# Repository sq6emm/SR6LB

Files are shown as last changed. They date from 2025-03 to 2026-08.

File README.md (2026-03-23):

This is technical documentation of SR6LB microwave beacon

Meshtastic trace url: [https://lorastats.pl/Node/192968]

# Source code of beacon

[https://github.com/sq6emm/MGMBeacon]

# History

+ 2025-05-02 - beacon installed and running, however 23cm reported .816 instead of .830 and 10GHz reported .723 instead of .830, 24GHz reported +300kHz higher - confirmed that GPS is not working
+ 2025-05-05 - reported that 10GHz is down
+ 2025-05-19 - professional GPS antenna connected - beacon has lock and is transmiting digital JT4, 10GHz is still down
+ 2025-05-22 - beacon is DOWN, SR6LHZ / SR6XHZ is operational again, beacon went for maintanance to resolve the 10GHz issue
+ 2025-10-05 - beacon is UP, 10GHz was fixed (it seems there was some cold soldering), Meshtastic was added that is sending telemtry on voltage and current, there is sill issue with GPSDO, no digital mode is transmitted and frequency seems to jump from time to time when GPSDO looses its lock
+ 2025-12-04 - beacon is DOWN, it was identified that there is no power at the beacon (Meshtastic is also not working while its only dependency is 12V)
+ 2026-02-21 - beacon is UP, failed power supply replaced, GPSDO as a source of 10MHz replaced by OCXO, software updated beacon now transmits CW + JT4 + Q65, but on 10GHz and 24GHz during Q65 it does not work, source code glitch, to be fixed soon, Meshtastic configuration now include GPS location coordinates
+ 2026-03-21 - beacon is UP, GPSDO replaced with eCzasPL Receiver, but it is unable to get the fix... to strong EM field for 225kHz... so beacon is running CW only - one more plan to replace eCzasPL with GPS receiver (something new like NEO-F9M) just to get a clock information, Q65 code is fixed... but as there is no clock information unable to confirm (locally tested)

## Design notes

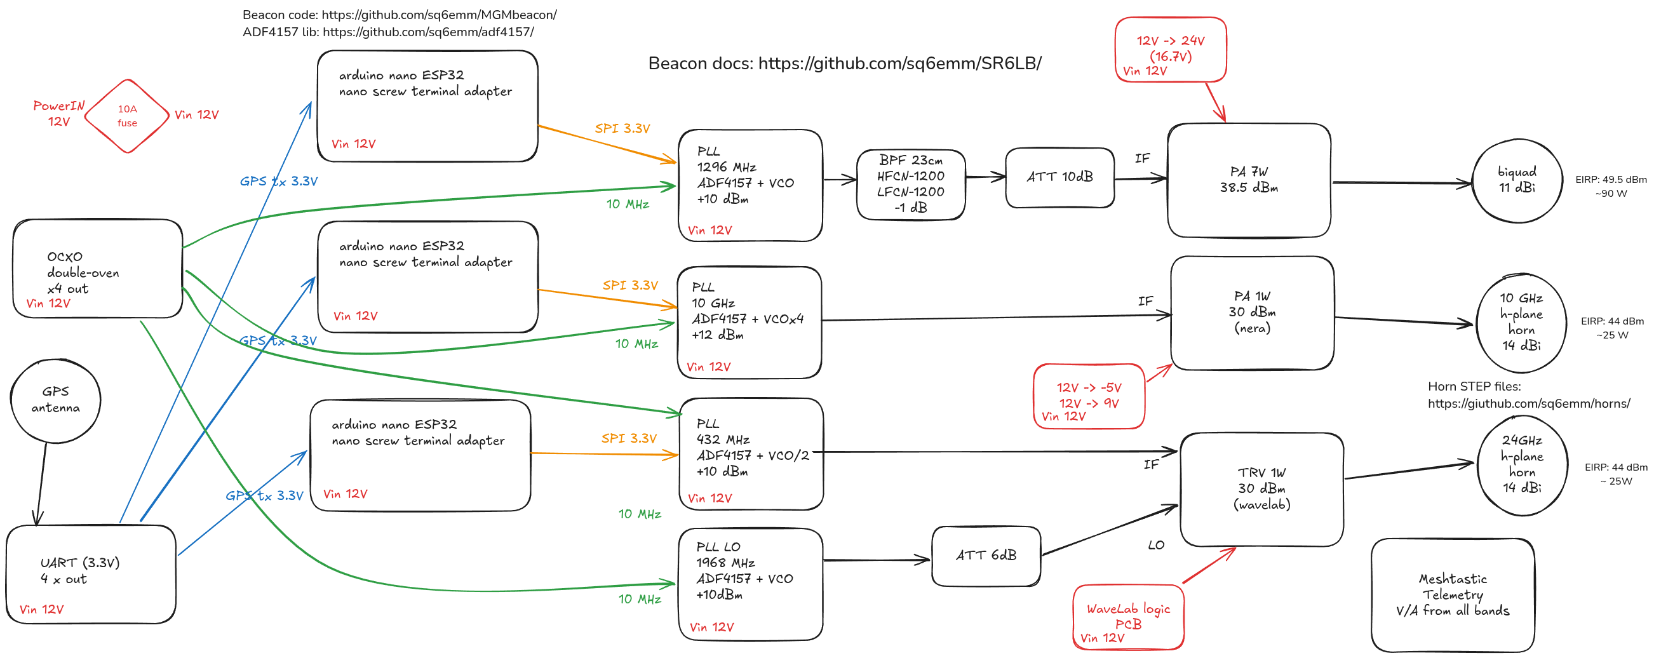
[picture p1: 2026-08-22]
SR6LB-block-diagram.png

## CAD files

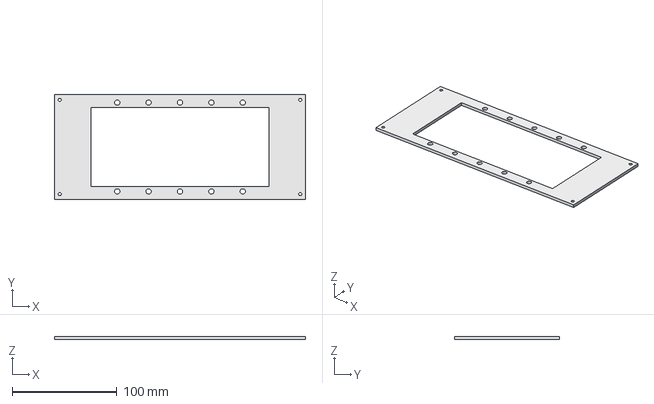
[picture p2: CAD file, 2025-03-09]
3dprints/beacon-10GHz PA mount.FCStd
240.0 x 100.0 x 3.00 mm

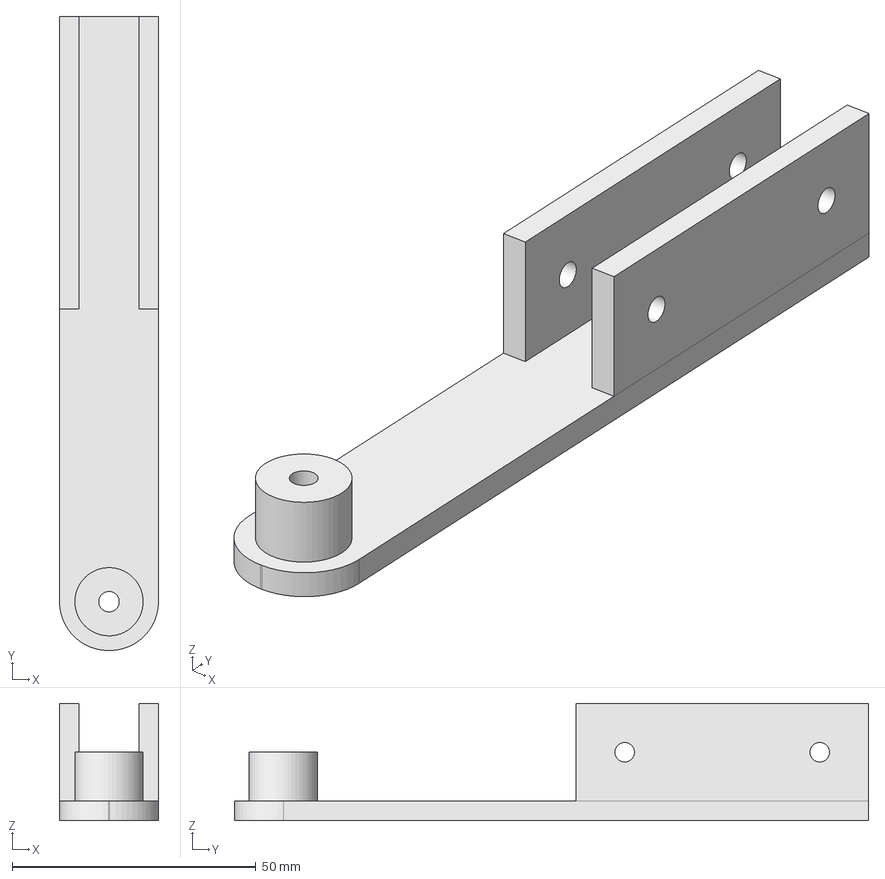
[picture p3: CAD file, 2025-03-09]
3dprints/beacon-24ghz-horn-mount-Body.step
20.3 x 130.0 x 24.0 mm

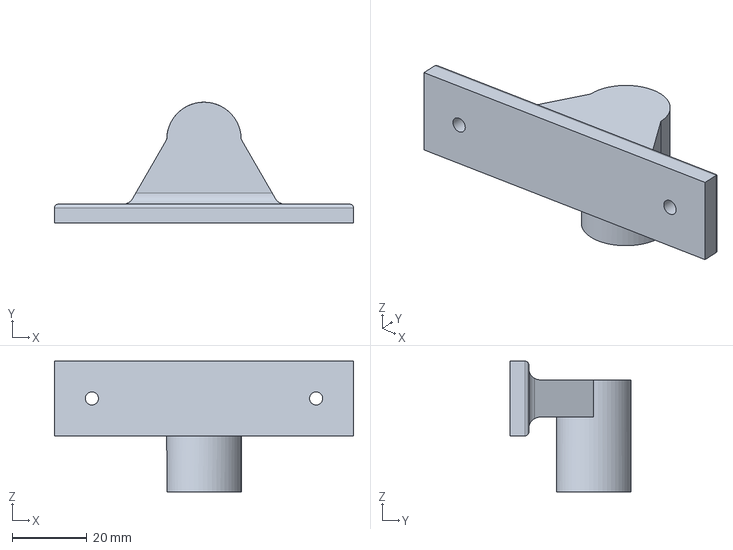
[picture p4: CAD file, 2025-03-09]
3dprints/beacon-mocowanie-biquad.FCStd
80.0 x 32.3 x 35.0 mm

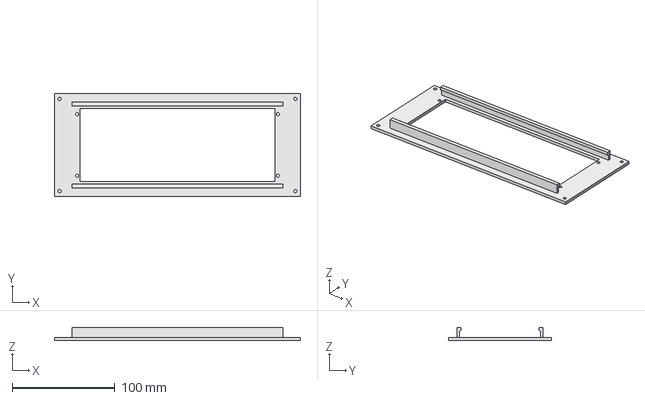
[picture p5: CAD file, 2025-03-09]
3dprints/beacon-radiator2-Body.step
240.0 x 100.0 x 12.5 mm

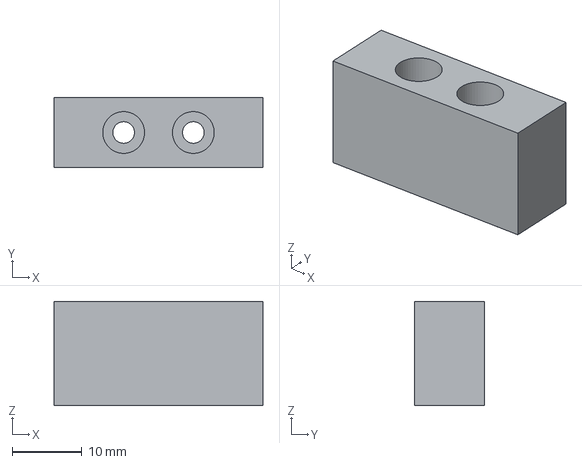
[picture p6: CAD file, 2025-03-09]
3dprints/beacon-podstawka-laczaca-Body.step
30.0 x 10.0 x 15.0 mm

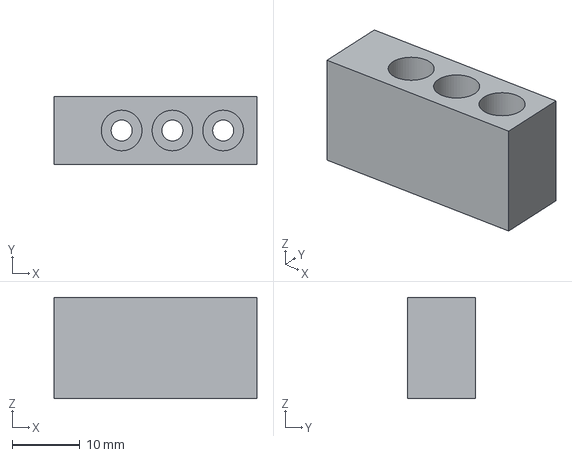
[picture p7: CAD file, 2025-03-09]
3dprints/beacon-podstawka-narozna-Body.step
30.0 x 10.0 x 15.0 mm

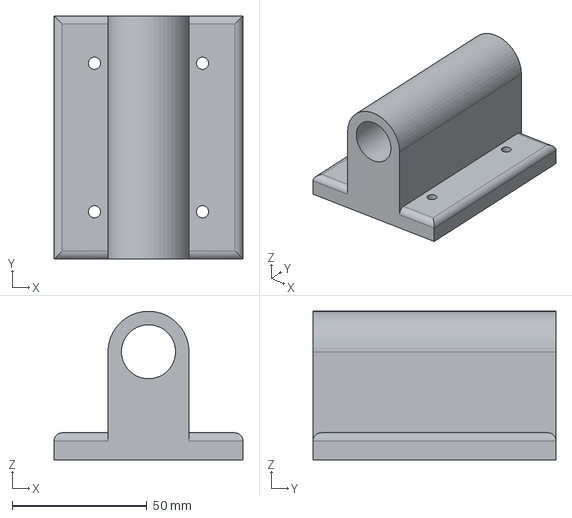
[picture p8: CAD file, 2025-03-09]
3dprints/beacon-podstawka-biquad-Body.step
70.0 x 90.0 x 55.0 mm

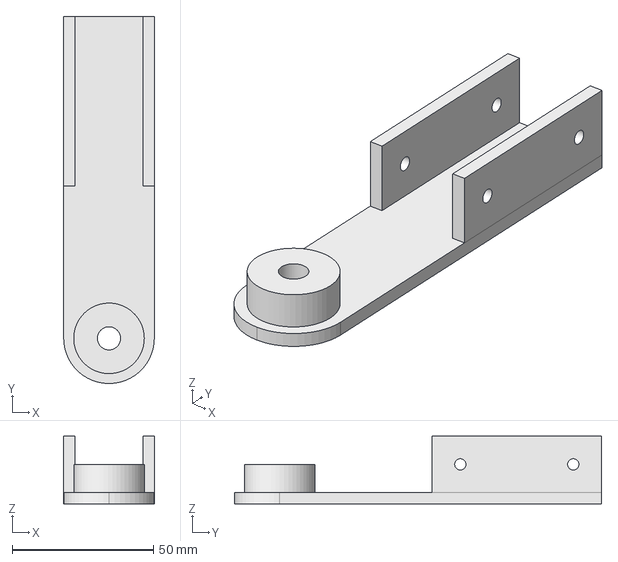
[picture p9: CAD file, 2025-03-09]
3dprints/beacon-10ghz-horn-mount-Body.step
32.1 x 130.0 x 24.0 mm

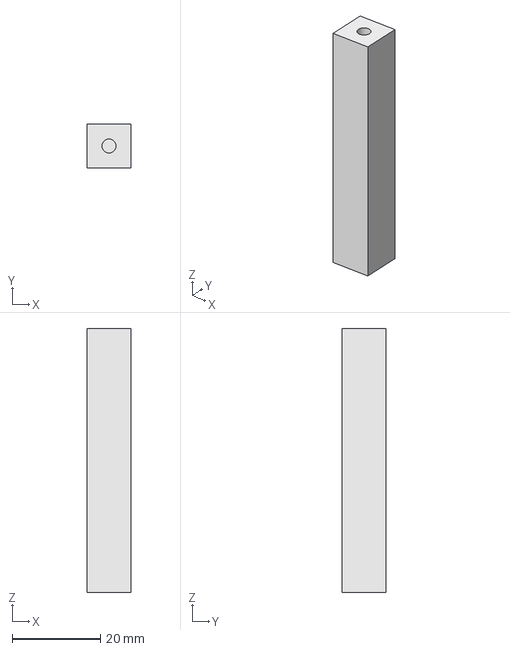
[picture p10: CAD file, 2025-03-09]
3dprints/beacon-support-Body.step
10.0 x 10.0 x 60.0 mm

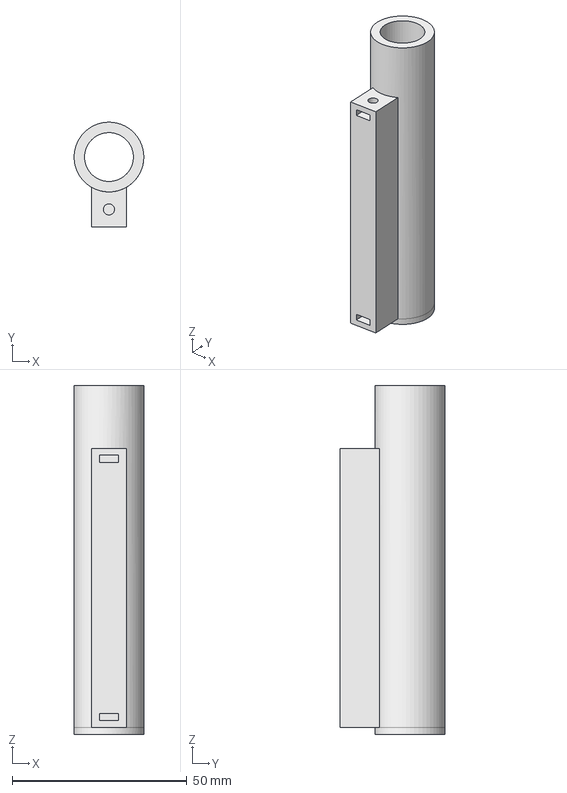
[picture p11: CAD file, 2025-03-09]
3dprints/beacon-24ghz-case-mount.FCStd
20.0 x 30.0 x 100.0 mm

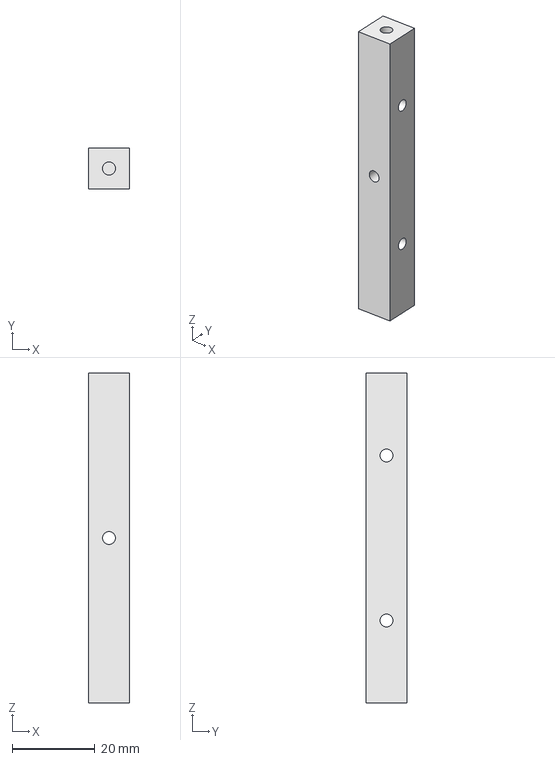
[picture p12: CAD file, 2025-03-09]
3dprints/beacon-support-v3.FCStd
10.0 x 10.0 x 80.0 mm

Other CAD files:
3dprints/beacon-24ghz-horn-mount.FCStd
3dprints/beacon-support.FCStd
3dprints/beacon-10ghz-horn-mount.FCStd
3dprints/beacon-podstawka-biquad.FCStd
3dprints/beacon-radiator2.FCStd
3dprints/beacon-podstawka-narozna.FCStd
3dprints/beacon-10GHz PA mount-Body.step
3dprints/beacon-10ghz-case-mount-Body.step
3dprints/beacon-10ghz-case-mount.FCStd
3dprints/beacon-24ghz-case-mount-Body.step
3dprints/beacon-case.FCStd
3dprints/beacon-mocowanie-biquad-Body.step
3dprints/beacon-podstawka-laczaca.FCStd
3dprints/beacon-support-v2-Body.step
3dprints/beacon-support-v2.FCStd
3dprints/beacon-support-v3-Body.step

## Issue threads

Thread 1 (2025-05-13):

GPS does not lock

sq6emm, 2025-05-13:
After installation it was identified that GPS is not providing TIME data and there is no LOCK on GPSDO.

It was identified by beacons transmitting VVVVV and not being on a correct frequency.

(This is the designed behaviour if there are issues with GPS)

sq6emm, 2025-05-13:
It was an expected issue as in the location of beacon there is extremly high RF field. Close by are TV transmitters with power around 18kW and frequency range 400-600MHz and also CCIR radio about 4kW.

Where beacon is installed RF field level is ~120V/m

sq6emm, 2025-05-13:
Replacement antenna

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

sq6emm, 2025-05-13:
In general lack of GPS lock caused:

- 1296MHz reported .816 instead of .830
- 10GHz reported .723 instead of .830
- 24GHz reported ~+300kHz higher

sq6emm, 2025-05-19:
GPS again has lost its lock, its tunning back now... but lost lock

sq6emm, 2025-05-19:
Its locked again... but what happened?
~12:30 today

sq6emm, 2025-05-19:
Again around 15:45

sq6emm, 2025-05-19:
Lock lost 15:08 again.

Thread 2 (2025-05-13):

10GHz band stopped working after few days.

sq6emm, 2025-05-13:
10GHz band stopped working after few days (after drastic outside temperature change).

Beacon is located in a room where there is no outside separation except for PLEXI window, so temperature inside is reacting fast for outside changes.

Not yet investigated.

We expect it to be connected with https://github.com/sq6emm/SR6LB/issues/1

sq6emm, 2025-05-19:
Its not connected with #1 .

sq6emm, 2025-05-21:
10GHz came back to alive.... by itself.

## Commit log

2025-12-04 Add Meshtastic trace URL and history update
    Added Meshtastic trace URL and updated history entry.
2026-02-22 Update Meshtastic URL and beacon history
    Updated Meshtastic trace URL and added recent history entries.
2026-03-23 Revise beacon operational history in README
    Updated operational status and maintenance notes for the beacon, including recent changes to power supply and GPSDO.
